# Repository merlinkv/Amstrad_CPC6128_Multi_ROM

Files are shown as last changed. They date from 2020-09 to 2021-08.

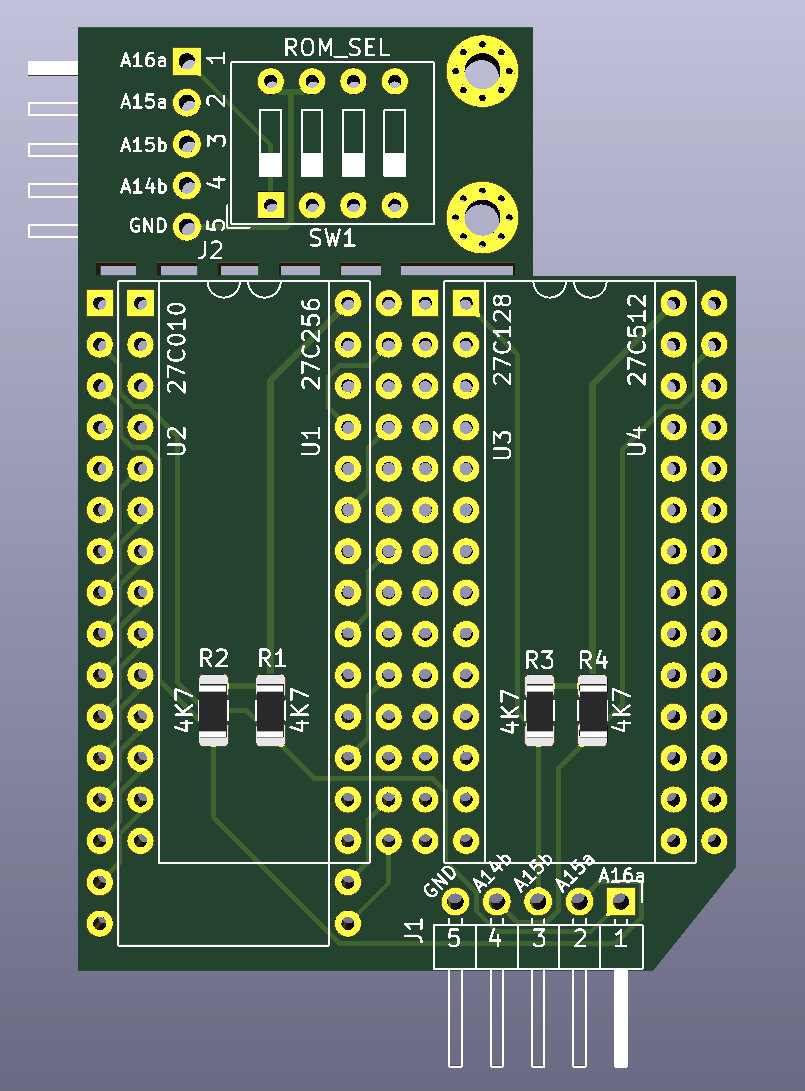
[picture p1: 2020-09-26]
Asmtrad_CPC6128_MultiROM_Front.jpg

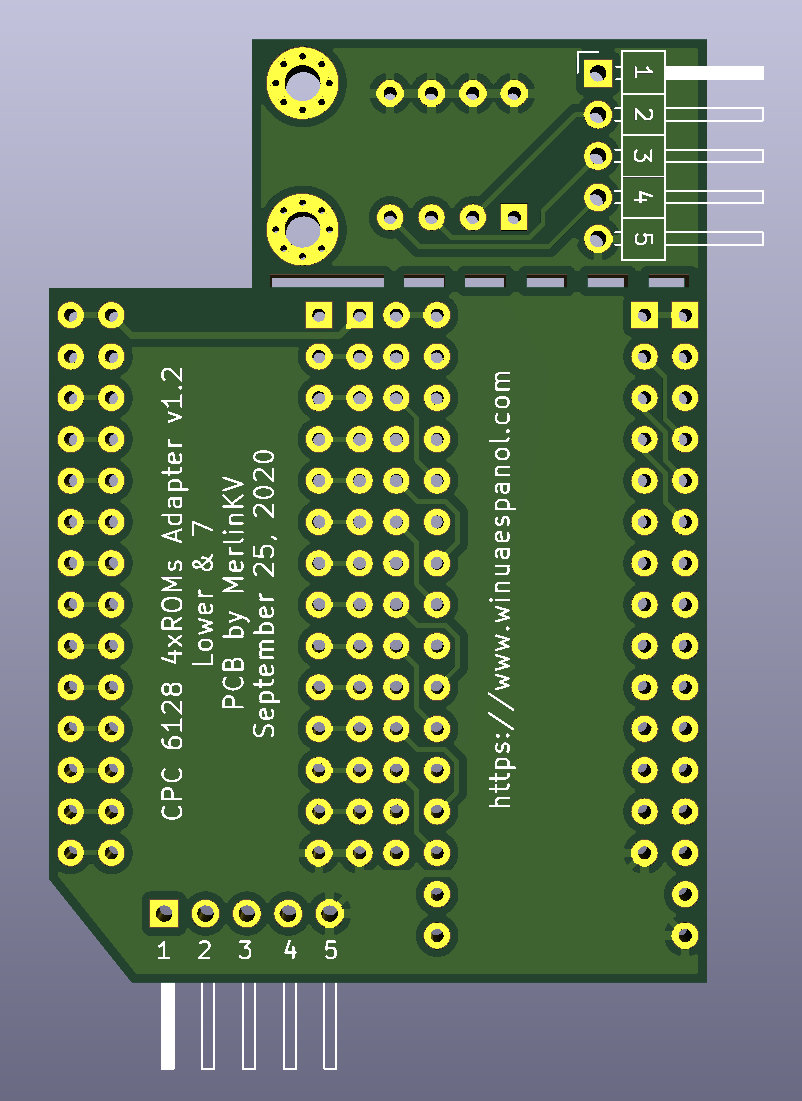
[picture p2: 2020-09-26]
Asmtrad_CPC6128_MultiROM_Back.jpg

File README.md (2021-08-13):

<br />This work is licensed under a <a rel="license" href="http://creativecommons.org/licenses/by-nc-sa/4.0/">Creative Commons Attribution-NonCommercial-ShareAlike 4.0 International License</a>.

* If you remix, transform, or build upon the material, you must distribute your contributions under the same license as the original.
* You may not use the material for commercial purposes.
* You must give appropriate credit, provide a link to the license, and indicate if changes were made. You may do so in any reasonable manner, but not in any way that suggests the licensor endorses you or your use.

# ATTENTION

This project was made for the retro community and not for commercial purposes. So only retro hardware forums and individual people can build this project.

ITS SALE ON EBAY OR OTHER AUCTION SITES IS PROHIBITED

# Note

I take no responsibiltiy for any damage to any equipment that results from the use of this board. USE AT YOUR OWN RISK!

# Amstrad_CPC6128_Multi_ROM_v1.2

Internal MultiROM adapter for Amstrad CPC6128

With this adapter we can have 4 ROMs in the ROMs: LowerROM+Basic (ROM0) and ROM7; and switch between ROMs as desired.

# LowerROM and ROM0

The LowerROM and ROM0 are located inside chip 40025 (40038 in the Spanish version) that corresponds to IC103. In the LowerROM the CPC OS is housed and in ROM0 the Basic, both 16Kb.

My idea is to be able to have 4 Lower ROMs without altering the Basic (you can do it if you want), so I will use an EEPROM W27C010 (128K), they would be programmed as:

* (LwROM 1 + Basic) + (LwROM 2 + Basic) + (LwROM 3 + Basic) + (LwROM 4 + Basic)

I have divided it into the 4 groups so that you can see it more clearly since we will access those ROMs in blocks of 32Kb.

# ROM7

The ROM7 is inside the 40015 chip that corresponds to the IC204 and is the one in charge of controlling the disks. It normally stores the 16Kb AMSDOS rom.

My idea is to have 4 ROMs so I will use an EEPROM W27C512 (64k) and they would be programmed as:

* ROM7_1 + ROM7_2 + ROM7_3 + ROM7_4

# Notes:

* It works for v1 and v2 revision boards but NOT on v3, you can check it on CPC6128 Motherboards
* You have to desolder the two original ICs of the motherboard and put sockets or solder my PCB directly on the motherboard.

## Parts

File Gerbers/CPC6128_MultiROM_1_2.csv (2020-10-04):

Id | Designator | Package | Quantity | Designation | Supplier and ref
1 | R4,R3,R2,R1 | R_1206_3216Metric_Pad1.42x1.75mm_HandSolder | 4 | 4K7
2 | SW1 | SW_DIP_SPSTx04_Slide_9.78x12.34mm_W7.62mm_P2.54mm | 1 | ROM_SEL
3 | HOLE1,HOLE2 | MountingHole_2.2mm_M2_Pad_Via | 2 | MountingHole_2.2mm_M2_Pad_Via
4 | J2 | PinHeader_1x05_P2.54mm_Horizontal | 1 | CABLE_CONN2
5 | U3 | DIP-28_W15.24mm | 1 | 27C128
6 | J1 | PinHeader_1x05_P2.54mm_Horizontal | 1 | CABLE_CONN1
7 | U4 | DIP-28_W15.24mm | 1 | 27C512
8 | U2 | DIP-32_W15.24mm | 1 | 27C010
9 | U1 | DIP-28_W15.24mm | 1 | 27C256

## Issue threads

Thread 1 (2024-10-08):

About CPC6128 Rev3

Silveriomrs, 2024-10-08:
Hi!
About the CPC6128 rev 3 Board PCB, I mean Z80330,
I have seen that there was a mod, where not info about.

I am checking out some troubles with devices on EDGE port. And I found that there is a power lack and problem on it, that affect Dandanators and more ROM devices connected to this port.

Checking a little deeper I found that in the board that I am analyzing is not a cable present. It seems to be a mod, that on the Internet I can find placed. It is a cable from the ROM to a decoupling capacitor.

So I suspect that perhaps your multirom doesn't work due to the same issue.
Since it is a just a picture and not info about it, I am not sure if those later boards has another mod to complete the task that produce those annoying effects.

Just in case you consider it interesting in order to solve both matters... here is a picture.
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

Few things more, in other PCBS the rom has separated connection between pin1 and pin28. The schem is wrong about pin1 power role. But in this Z80330 the rom has linked pin1 and pin28. Datasheet says (If I am not wrong about the EPROM) that pin#1 is NC.

Makes it sense?
